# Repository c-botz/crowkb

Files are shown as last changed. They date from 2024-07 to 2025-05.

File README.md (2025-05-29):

# crowkb keyboards
The crowkb keyboards are split, staggered and splayed keyboard with low placed thumbkeys. I designed them because I felt a lot of the keyboards in this space have an uncomfortable thumb placement for my size of hands.

parts and instructions in docs folder
## crowkb_wing
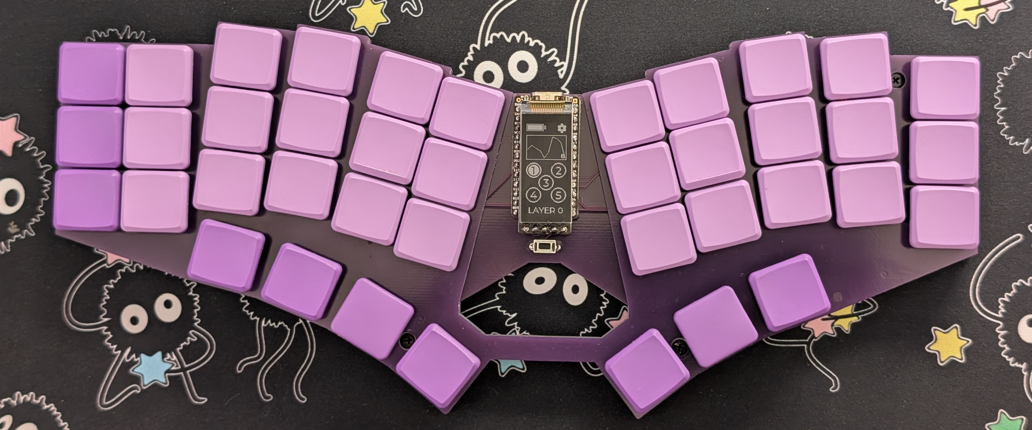
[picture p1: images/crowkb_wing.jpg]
crowkb_wing_back


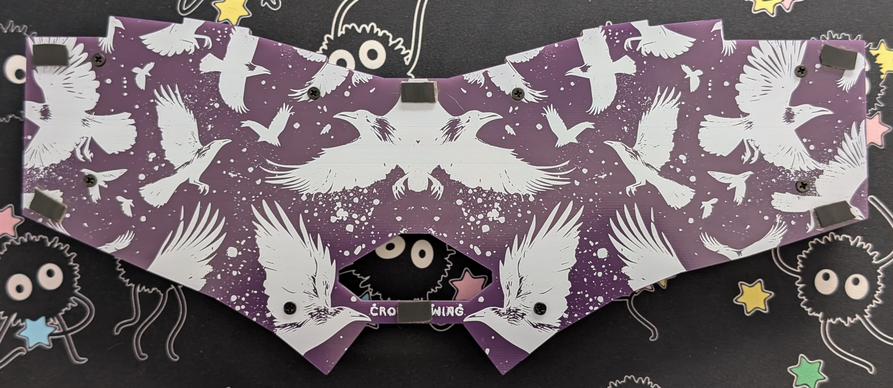
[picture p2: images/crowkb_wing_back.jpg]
crowkb_wing_back


## crowkb_38
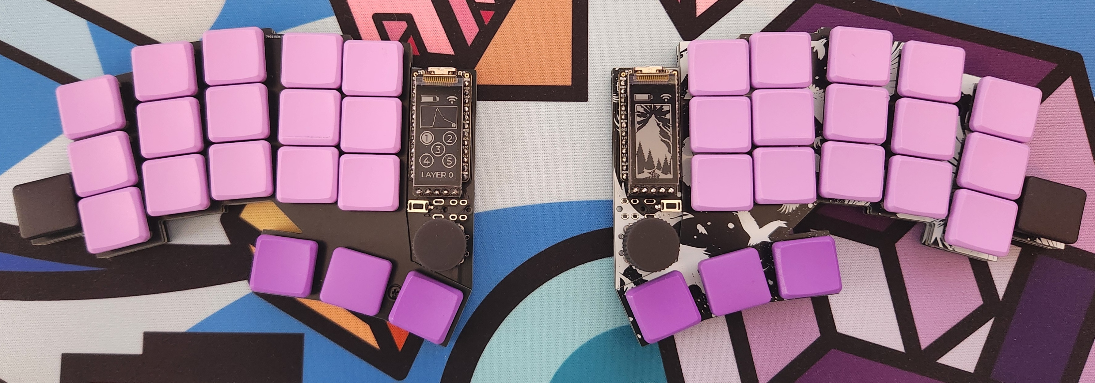
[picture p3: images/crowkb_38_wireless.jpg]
crowkb_38_wireless


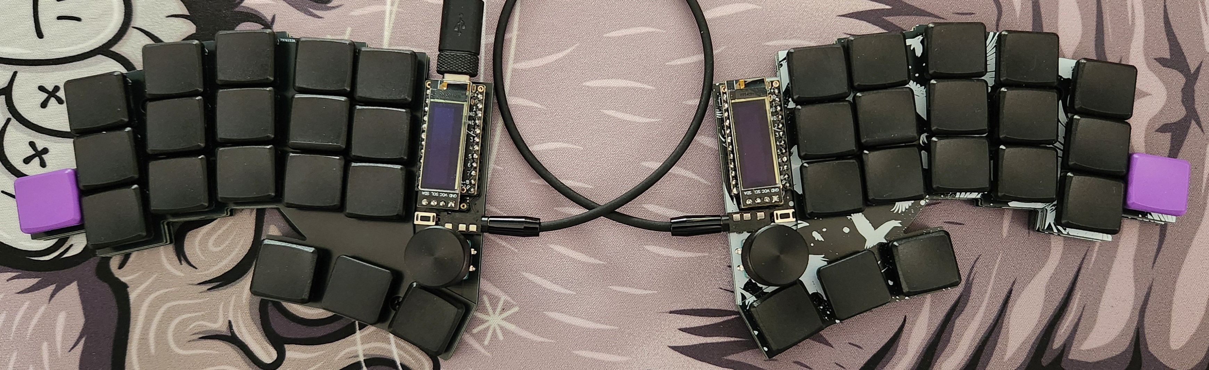
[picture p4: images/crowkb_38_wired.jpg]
crowkb_38_wired


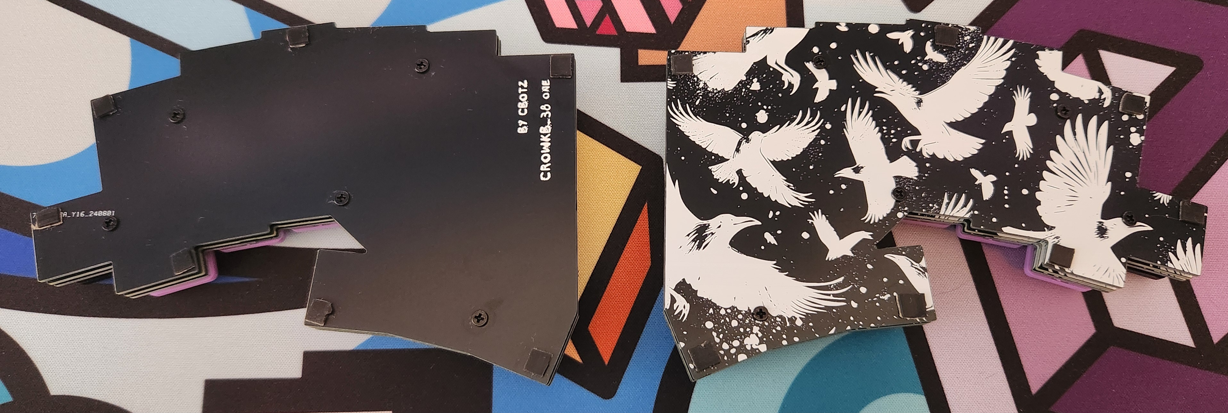
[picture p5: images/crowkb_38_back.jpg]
crowkb_38_back


## crowkb_46
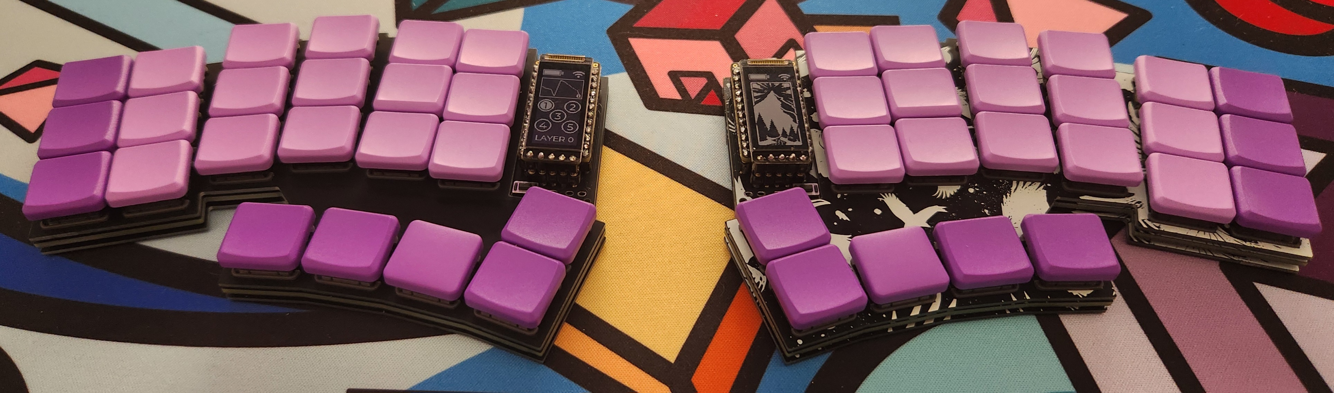
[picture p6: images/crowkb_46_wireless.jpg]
crowkb_46_wireless


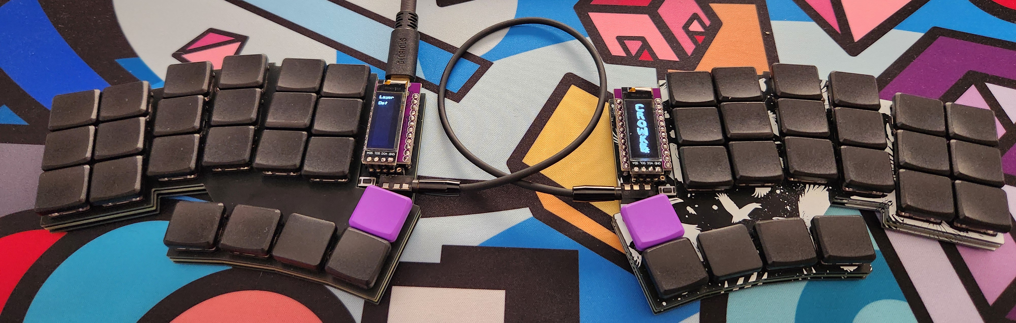
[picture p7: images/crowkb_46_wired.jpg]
crowkb_46_wired


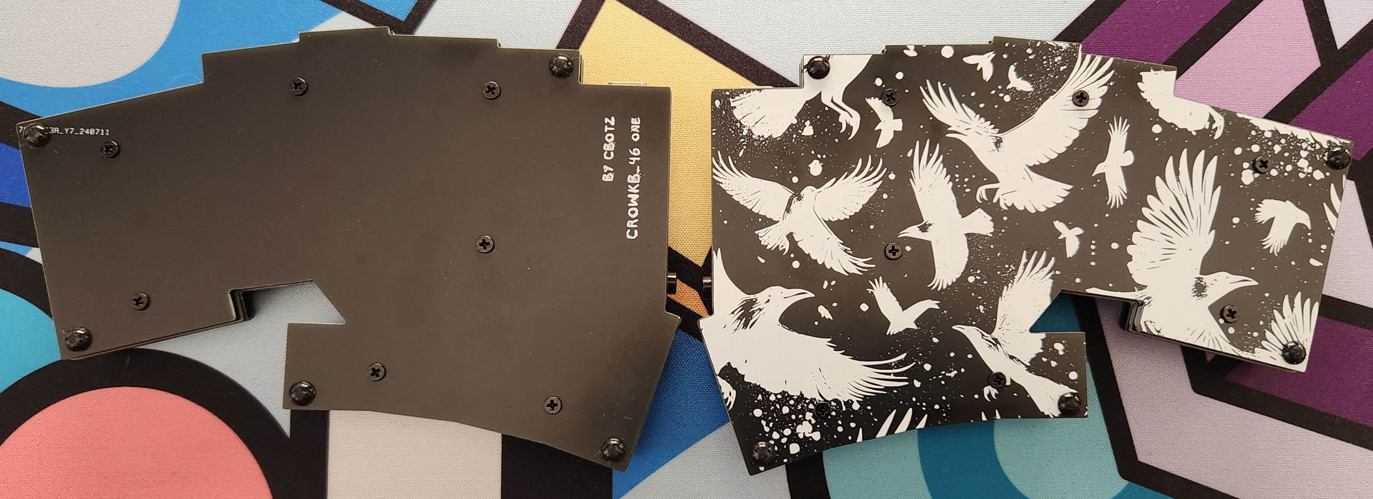
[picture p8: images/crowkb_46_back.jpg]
crowkb_46_back


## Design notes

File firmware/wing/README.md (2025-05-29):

## flashing nice!nano
  1. plug nice!nano into your pc
  2. press the reset button twice (or short RST to GND twice)
  3. you should see a usb device named NICENANO show up on your pc
  4. copy the corresponding (right or left) .uf2 files into the NICENANO usb device

### If you'd like to modify the keymap and what not:

[my ZMK repo](https://github.com/c-botz/zmk-config-crowkb_wing)

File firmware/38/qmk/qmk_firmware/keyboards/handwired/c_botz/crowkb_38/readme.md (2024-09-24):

# c_botz/crowkb_38

c_botz/crowkb_38

*A short description of the keyboard/project*

* Keyboard Maintainer: [c-botz](https://github.com/c-botz)
* Hardware Supported: *The PCBs, controllers supported*
* Hardware Availability: *Links to where you can find this hardware*

Make example for this keyboard (after setting up your build environment):

    make c_botz/crowkb_38:default

Flashing example for this keyboard:

    make c_botz/crowkb_38:default:flash

See the [build environment setup](https://docs.qmk.fm/#/getting_started_build_tools) and the [make instructions](https://docs.qmk.fm/#/getting_started_make_guide) for more information. Brand new to QMK? Start with our [Complete Newbs Guide](https://docs.qmk.fm/#/newbs).

## Bootloader

Enter the bootloader in 3 ways:

* **Bootmagic reset**: Hold down the key at (0,0) in the matrix (usually the top left key or Escape) and plug in the keyboard
* **Physical reset button**: Briefly press the button on the back of the PCB - some may have pads you must short instead
* **Keycode in layout**: Press the key mapped to `QK_BOOT` if it is available

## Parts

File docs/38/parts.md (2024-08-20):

## parts
Most of this can be ordered from aliexpress. For the pcbs and plates, you can download the gerber files from this repo and have them printed by a website like jlcpcb.
### required
| qt | part | wireless | wired | note | 
| -- | ---- | --- | --- | - |
| 2 | crowkb_38 pcbs  | X | X | recommend 1.6mm thick |
| 38 | Kailh choc v1 style switches | X | X | |
| 40 | SOD-123 1n4148w smd diodes | X | X | |
| 2 | ec11 or ec12 encoders | X | X | ec11 has an integrated switch and are big, ec12s are low profile but don't have an integrated switch |
| 2 | encoder knobs | X | X | just make sure they work with the encoder you pick (D, knurled, etc)  |
| 2 | 3 x 6 x 4.3 momentary (reset) switch tht | X | X | |
| 2 | PJ320A TRRS tht | | X | |
| 2 | MSK-12C02 smd slide switch | X | | |
| 2 | 301230 battery | X | | |
| 38 | choc profile keycaps | X | X | I like the MBK stuff |
| 1 | trrs cable (not trs) | | X | |
| 10+ | small rubber feet (i.e. bumpons) | X | X | To maximize low profile, I used 1mm silicone rubber gasket seal. If you're not using a bottom plate, you'll need something at least 2mm tall |

### optional
| qt | part | wireless | wired | note |
| -- | ---- | --- | --- | -- |
| 2 | bottom plates | X | X | Recommend 1.2mm thick. Will also need screws and spacers, listed lower |
| 2 | switch plates | X | X | Definitely 1.2mm thick, may be an extra ~$7 charge when you order these, because of the intricate cuts |
| 2 | nice!view eInk screens | X | |
| 2 | ssd1306 oled screens | | X |
| 38 | Kailh choc hot swap sockets | X | X | |
| | double side foam adhesive tape (battery) | X | | I used .5mm thick 10mm wide |
| 10 | 2mm or 3mm M2 spacer or insert nuts (threaded) | X | X | For bottom plate |
| 10 | 2mm M2 screws | X | X | For bottom plate |
| 10 | 3mm M2 screws | X | X | To mount pcb to bottom plate |
| | 2.54mm female socket headers | X | X | definitely recommend socketing your mcu and display |
| | 1n4148 diode legs (for socketing mcu) | X | X | [socketing mcu instructions](https://docs.splitkb.com/hc/en-us/articles/360011263059-How-do-I-socket-a-microcontroller)|

### mcu's i've used
*if you want to use vial, I only have it working on rp2040s. I can't get it small enough for promicro.

| qt | part | wireless | wired | note |
| -- | ---- | --- | --- | -- |
| 2 | nice!nano | X | | [zmk firmware in repo](../firmware/zmk) |
| 2 | promicro | | X | [qmk firmware in repo](../firmware/qmk)  |
| 2 | rp2040, promicro compatible | | X | tested kmk and qmk on helios clones, [qmk firmware in repo](../firmware/qmk)  |

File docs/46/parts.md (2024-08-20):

## parts
Most of this can be ordered from aliexpress. For the pcbs and plates, you can download the gerber files from this repo and have them printed by a website like jlcpcb.
### required
| qt | part | wireless | wired | note | 
| -- | ---- | --- | --- | - |
| 2 | crowkb_46 pcbs  | X | X | recommend 1.6mm thick |
| 46 | Kailh choc v1 style switches | X | X | |
| 46 | SOD-123 1n4148w smd diodes | X | X | |
| 2 | 3 x 6 x 4.3 momentary (reset) switch tht | X | X | |
| 2 | PJ320A TRRS tht | | X | |
| 2 | MSK-12C02 smd slide switch | X | | |
| 2 | 301230 battery | X | | |
| 46 | choc profile keycaps | X | X | I like the MBK stuff |
| 1 | trrs cable (not trs) | | X | |
| 10+ | small rubber feet (i.e. bumpons) | X | X | To maximize low profile, I used 1mm silicone rubber gasket seal. If you're not using a bottom plate, you'll need something at least 2mm tall |

### optional
| qt | part | wireless | wired | note |
| -- | ---- | --- | --- | -- |
| 2 | bottom plates | X | X | Recommend 1.2mm thick. Will also need screws and spacers, listed lower |
| 2 | switch plates | X | X | Definitely 1.2mm thick, may be an extra ~$7 charge when you order these, because of the intricate cuts |
| 2 | nice!view eInk screens | X | |
| 2 | ssd1306 oled screens | | X |
| 46 | Kailh choc hot swap sockets | X | X | |
| | double side foam adhesive tape (battery) | X | | I used .5mm thick 10mm wide |
| 14 | 2mm or 3mm M2 spacer or insert nuts (threaded) | X | X | For bottom plate |
| 14 | 2mm M2 screws | X | X | For bottom plate |
| 14 | 3mm M2 screws | X | X | To mount pcb to bottom plate |
| | 2.54mm female socket headers | X | X | definitely recommend socketing your mcu and display |
| | 1n4148 diode legs (for socketing mcu) | X | X | [socketing mcu instructions](https://docs.splitkb.com/hc/en-us/articles/360011263059-How-do-I-socket-a-microcontroller)|

### mcu's i've used
| qt | part | wireless | wired | note |
| -- | ---- | --- | --- | -- |
| 2 | nice!nano | X | | [zmk firmware in repo](../firmware/zmk) |
| 2 | promicro | | X | [qmk firmware in repo](../firmware/qmk)  |
| 2 | rp2040, promicro compatible | | X | tested kmk and qmk on helios clones, [qmk firmware in repo](../firmware/qmk)  |

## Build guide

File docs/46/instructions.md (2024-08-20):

**this document is in progress**
 
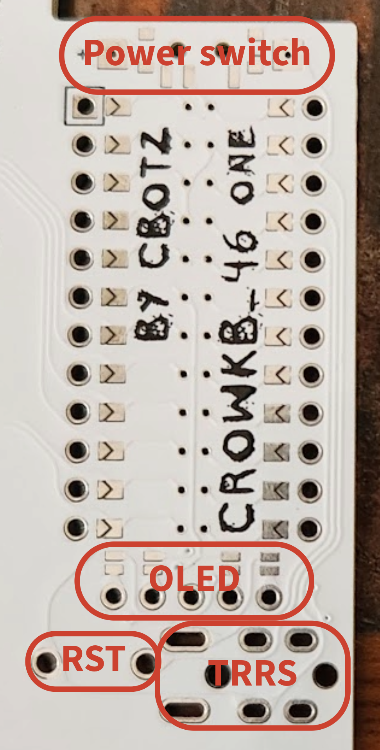
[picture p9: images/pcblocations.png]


## fix for issue with left side OLED P2/SDA (pre 7/26/24 pcbs)
 - If you had the pcb printed before I uploaded the fixed gerber and kicad on 07/26/24, you will need to run a bit of extra solder or a jumper for the **left** side keyboard display to work. My appologies.
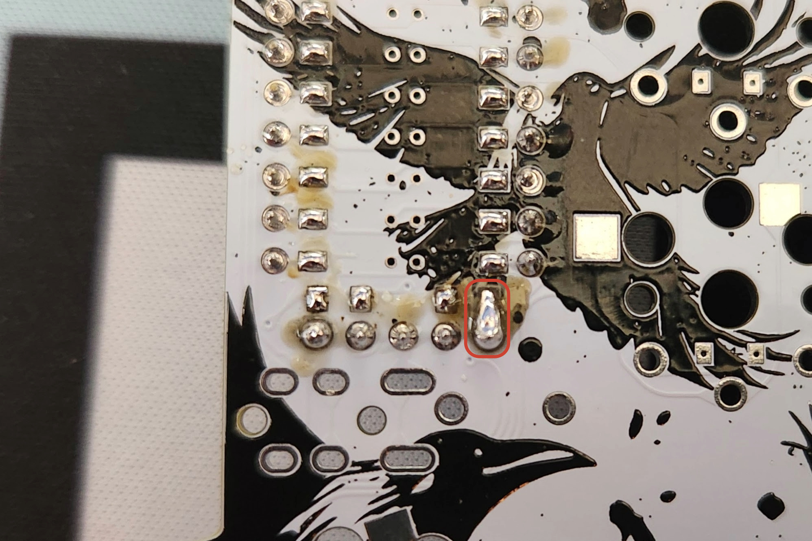
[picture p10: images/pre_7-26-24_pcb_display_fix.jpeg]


## battery and power switch
 - For the battery pads, the positive and negative pads are vias. Basically, regardless of side, the positive pad is the one closest to the keys and the negative is the one closer to the outer edge. I mention it because the silkscreen on the crow side covers the + and - markers.


 - For the power switch, I recommend soldering it to the underside of the pcb, to give room for the battery. It works on either side.
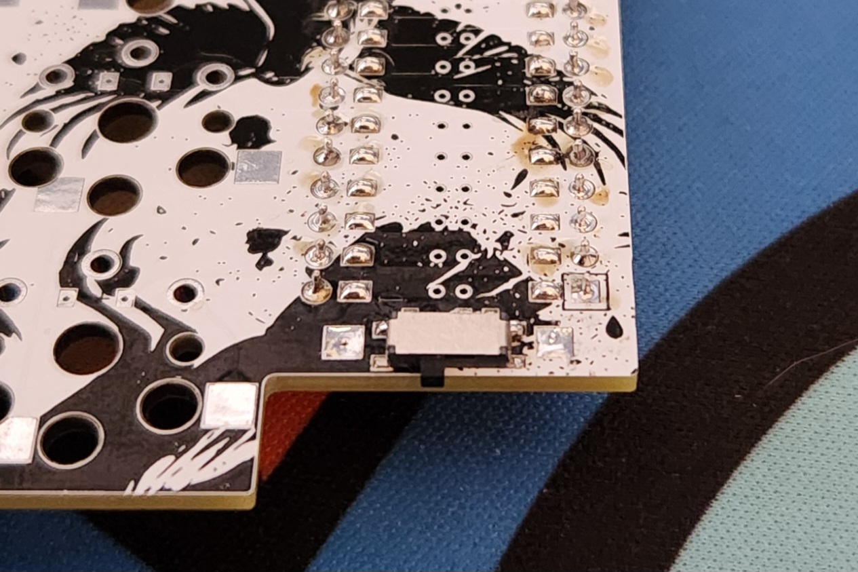
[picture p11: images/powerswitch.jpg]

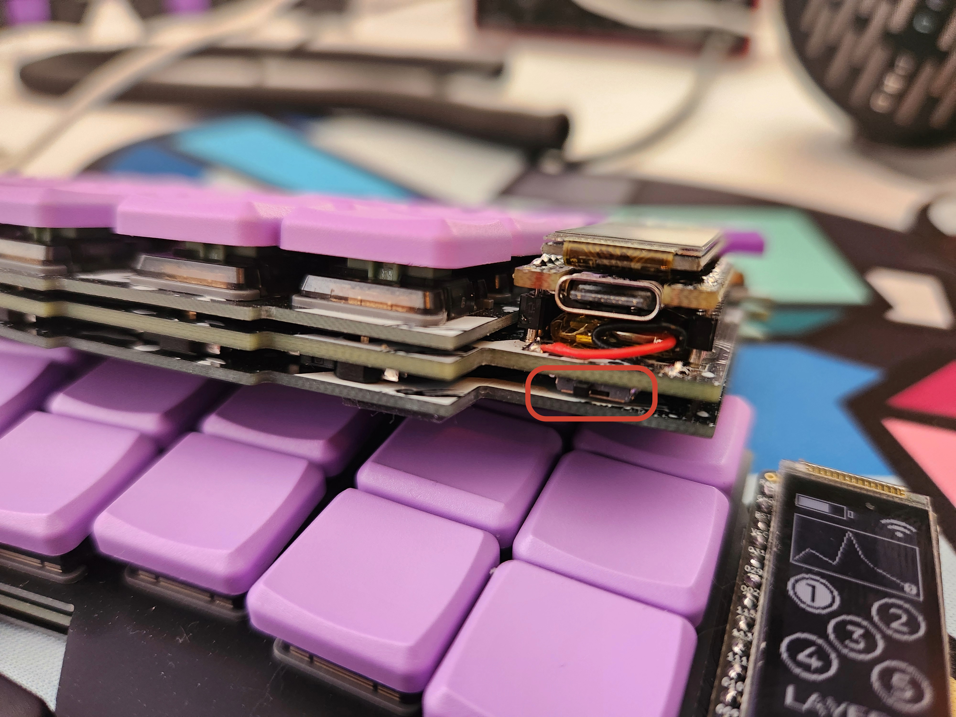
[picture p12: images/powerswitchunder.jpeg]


## bridge pads for mcu and oled
 - This uses the promicro_pretty footprint. Essentially, you need to bridge the pads on the correct side, depending on the orientation you want your mcu in. If you want the MCU flipped downward, bridge the pads on the bottom side of the pcb. If you want the mcu facing upward, bridge the pads on the top side of the pcb. (this is regardless of if you're using the pcb for the left or right side keyboard)

 - For the display through holes, you'll see pads above them on either side of the pcb. Bridge the pads on the bottom side of the pcb. (this is regardless of if you're using the pcb for the left or right side keyboard.

### here's an example of one where the mcu is faced down:
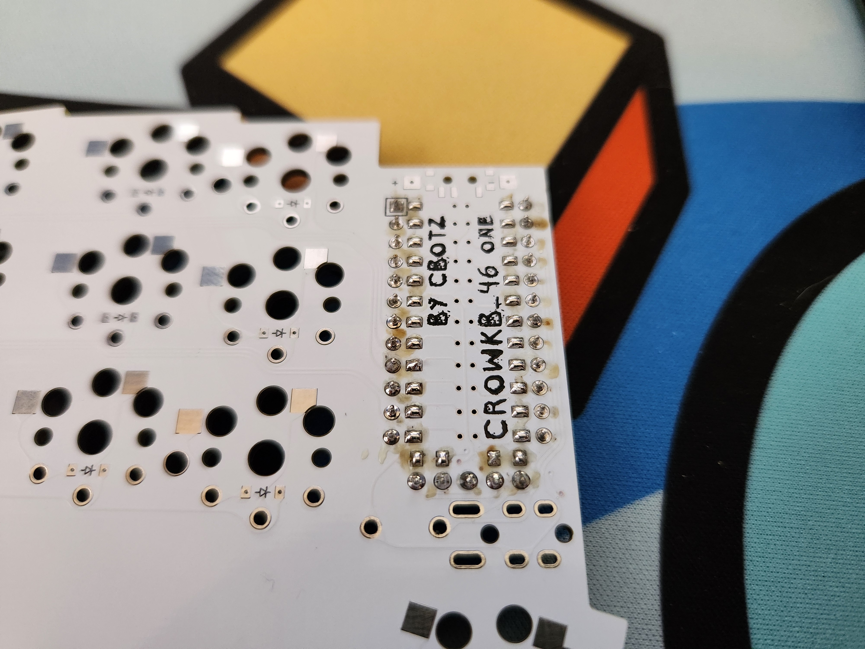
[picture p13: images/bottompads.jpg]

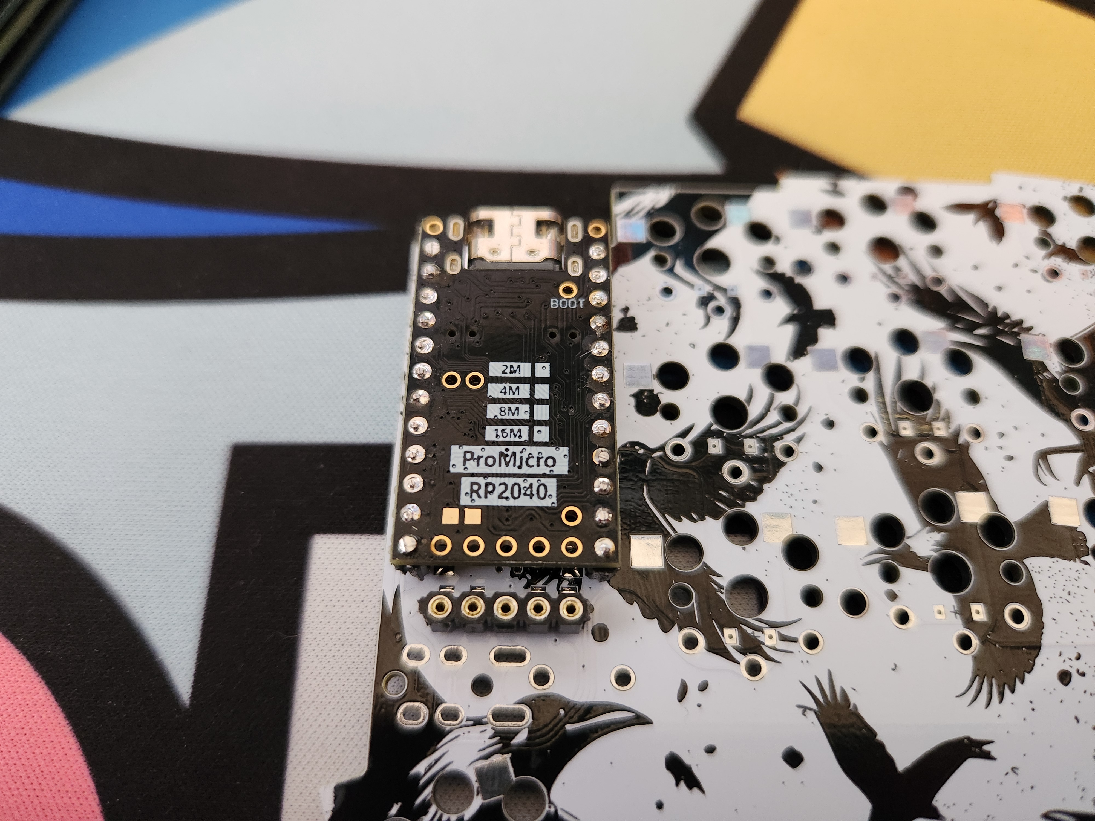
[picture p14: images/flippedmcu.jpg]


 ## ssd1306 pins
 - If you are using a ssd1306 oled, it will use the left 4 of the oled through holes (regardless of left or right keyboard). The fifth one on the right is for the CS connection that the nice!view requires.
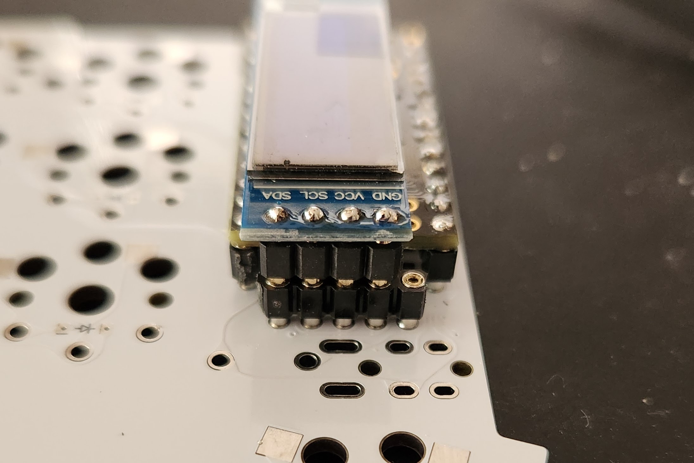
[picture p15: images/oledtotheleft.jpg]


 ## diodes
 - The diode direction is towards the mcu. I only mention it because the silkscreen on the crow side kind of hides it.

## bottom plate mounting
 - If using a bottom plate, You should have ordered it 1.2mm thick. Use the 2mm screws through the bottom plate into the spacers and then the 3mm screws through the pcb.

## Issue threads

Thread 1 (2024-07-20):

All KiCAD filea are empty.

azhizhinov, 2024-07-20:
Hello.
Thanks for sharing this cool project, but all KiCAD files are empty.
Have a nice day.

c-botz, 2024-07-20:
Thank you for pointing it out. Re-uploaded as zips seems to have fixed it.

Closed 2024-07-20.

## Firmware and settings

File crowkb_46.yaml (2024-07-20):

units:
    kx: cx
    ky: cy

points:
  key: 
    spread: cx
    padding: cy
  zones:
    matrix:
      anchor:
        rotate: 15
      columns:
        mod:
          key.column_net: P8
        pinky:
          key.column_net: P9
        ring:
          key.splay: -6
          key.origin: [3kx,-.75ky]
          key.column_net: P5
        middle:
          key.splay: -3
          key.origin: [1.75kx,-1.3ky]
          key.column_net: P6
        index:
          key.splay: -6
          key.origin: [-1.6kx,-.85ky]
          key.column_net: P7
        inner:
          key.stagger: -2 
          key.column_net: P4
      rows:
        bottom:
          row_net: P19
        home:
          row_net: P20
        top:
          row_net: P21
    thumbfan:
      anchor:
        ref: matrix_middle_bottom
        shift: [-.35kx, -1.8ky]
        rotate: -6
      columns:
        mod:
          key.column_net: P5
        near:
          key.splay: -6
          key.origin: [-.5kx,-.8ky]
          key.column_net: P6
        home:
          key.splay: -6
          key.origin: [-.5kx,-.8ky]
          key.column_net: P7
        far:
          key.splay: -6
          key.origin: [-.5kx,-.8ky]
          key.column_net: P4
          rows:
            thumb:
              row_net: P16
            esc:
              row_net: P10
      rows:
        thumb:
          row_net: P16
outlines:
  _switches:
    - what: rectangle
      where: true
      size: 14
      bound: false
  _mcu_cutout:
    - what: polygon
      points:
        - ref: matrix_inner_top
          shift: [1.69kx, 0.11ky]
        - ref: matrix_inner_top
          shift: [0.56kx, 0.55ky]
        - ref: matrix_inner_bottom
          shift: [ .56kx, -.5ky] 
        - ref: thumbfan_far_esc
          shift: [-0.5kx, 0.55ky]
        - ref: thumbfan_far_esc
          shift: [0.45kx, 0.55ky]
  crowkb_46_bottom_plate:
    - what: polygon
      points:
        # NE
        - ref: matrix_inner_top
          shift: [1.69kx, 0.11ky]
        - ref: matrix_inner_top
          shift: [0.56kx, 0.11ky]
        - ref: matrix_inner_top
          shift: [0.56kx, 0.55ky]
        - ref: matrix_inner_top
          shift: [-.45kx, .55ky]
        - ref: matrix_index_top
          shift: [0.55kx, 0.55ky]
        # N
        - ref: matrix_index_top
          shift: [-0.78kx, 0.55ky]
        - ref: matrix_middle_top
          shift: [0.55kx, 0.55ky]
        - ref: matrix_middle_top
          shift: [-0.55kx, 0.55ky]
        - ref: matrix_ring_top
          shift: [0.64kx, 0.55ky]          
        - ref: matrix_ring_top
          shift: [-0.56kx, 0.55ky]
        - ref: matrix_ring_top
          shift: [-0.56kx, 0.17ky]
        - ref: matrix_pinky_top
          shift: [0.55kx, 0.55ky]  
        # NW
        - ref: matrix_pinky_top
          shift: [-0.55kx, 0.55ky]
        - ref: matrix_mod_top
          shift: [0.45kx, 0.55ky]
        - ref: matrix_mod_top
          shift: [-0.55kx, 0.55ky]
        # SW
        - ref: matrix_mod_bottom
          shift: [-0.55kx, -0.55ky]
        - ref: matrix_mod_bottom
          shift: [0.55kx, -0.55ky]
        - ref: matrix_pinky_bottom
          shift: [-0.45kx, -0.55ky]
        - ref: matrix_pinky_bottom
          shift: [0.55kx, -0.55ky]
        - ref: matrix_ring_bottom
          shift: [-0.5kx, -0.55ky]
        - ref: matrix_ring_bottom
          shift: [0.5kx, -0.55ky]
        # SE
        - ref: thumbfan_mod_thumb
          shift: [.16kx, 0.55ky]
        - ref: thumbfan_mod_thumb
          shift: [-0.55kx, 0.55ky]
        - ref: thumbfan_mod_thumb
          shift: [-0.55kx, -0.55ky]
        - ref: thumbfan_near_thumb
          shift: [-0.55kx, -0.55ky]
        - ref: thumbfan_home_thumb
          shift: [-0.55kx, -0.55ky]
        - ref: thumbfan_home_thumb
          shift: [0.55kx, -0.55ky]
        - ref: thumbfan_far_thumb
          shift: [0.55kx, -0.55ky]
        - ref: thumbfan_far_esc
          shift: [0.55kx, 0.55ky]
        - ref: thumbfan_far_esc
          shift: [0.345kx, 0.55ky]        
      fillet: .5
  crowkb_46_switch_plate:
    - crowkb_46_bottom_plate
    - -_switches
    - -_mcu_cutout
pcbs:
  crowkb_46:
    outlines:
      main:
        outline: crowkb_46_bottom_plate
    footprints:
      choc_hs:
        what: choc
        where: true
        params:
          hotswap: true
          reverse: true
          keycaps: true
          from: "{{column_net}}"
          to: "{{colrow}}"
      choc:
        what: choc
        where: true
        adjust:
          rotate: 180
        params:
          reverse: true
          from: "{{colrow}}"
          to: "{{column_net}}"
      promicro:
        what: promicro_pretty
        where:
          ref: matrix_inner_top
          shift: [1.11kx, -1.055ky]
          rotate: 270
        params:
          GND: GND=
      oled:
        what: display_nice_view
        where:
          ref: matrix_inner_top
          shift: [1.11kx, -1.155ky]
        params:
          reversible: true
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

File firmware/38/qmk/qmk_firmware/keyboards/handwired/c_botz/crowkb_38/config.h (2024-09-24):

// Copyright 2024 Ethan Wright (@c-botz)
// SPDX-License-Identifier: GPL-2.0-or-later

#pragma once

#define MASTER_LEFT

#define OLED_FONT_H "lib/glcdfont.c"

#define ENCODERS_PAD_A { B6 }
#define ENCODERS_PAD_B { F7 }

#define ENCODERS_PAD_A_RIGHT { B6 }
#define ENCODERS_PAD_B_RIGHT { F7 }

#define TAPPING_TERM 200

/*
 * Feature disable options
 *  These options are also useful to firmware size reduction.
 */

/* disable debug print */
//#define NO_DEBUG

/* disable print */
//#define NO_PRINT

/* disable action features */
//#define NO_ACTION_LAYER
//#define NO_ACTION_TAPPING
//#define NO_ACTION_ONESHOT

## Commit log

2025-05-29 Update and rename firmware/README.md.txt to firmware/wing/README.md.txt
2025-05-29 Rename firmware/crowkb_wing nice_view_adapter nice_view-nice_nano_v2-zmk.uf2 to firmware/wing/crowkb_wing nice_view_adapter nice_view-nice_nano_v2-zmk.uf2
